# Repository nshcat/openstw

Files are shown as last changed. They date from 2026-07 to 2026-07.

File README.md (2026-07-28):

# openstw

A project aiming to design a physical replica of a German Sp Dr S60 relais signal box panel (_Stelltisch_) with a software simulation of local railway traffic behind it, in order to offer a compelling simulation of the day-to-day work of a signal box operator (_Fahrdienstleiter_).

## Project goals
- **A depiction of a Sp Dr S60 Stelltisch that is as realistic as possible** - This is pretty much the main goal for me. Unlike many other projects on the internet that already saw the light of day, I am not planning on making any compromises when it comes to the visual and functional design of the Stelltisch and its tiles. Even though that is likely never going to happen, I'd want it to be useable as a training aid for train routing controllers, even if only in theory.

- **Easy extensibility when adapting to new Betriebsstellen** - The system should be very modular and easy to configure, such that building replicas of any of the real German Betriebsstellen that employ a Sp Dr S60 signal box is as easy and frictionless as possible. Of course, local oddities will almost always require some degree of customization, such as custom tiles that feature specific colours and signal placements, but my goal is to reduce this work as much as possible, and make it as easy as possible.

- **As little expensive tools needed as possible** - I want the whole project to be buildable with nothing more than a run-of-the-mill 3D printer, access to a PCB manufacturing and assembly service and a set of screwdrivers. This includes not having to pay tons of money for software licenses!

- And of course, **Be completely Open-Source!** - To me, this also implies that all the tools used to make this project a reality should be open-source as well.

## Non-goals
- **Interfacing with model train setups** - I personally am neither interested in nor experienced with model train setups, and thus this project will not be designed or implemented with that in mind. Although the already existing software and hardware architecture design does leave the possibility open, if anyone else dares to try :)

- **Have everything be hand-solderable** - I have decided against this right from the start. The small size of the Stelltisch tiles make it almost a neccasity to use very small SMT components, and since access to PCB assembly is easy and comparatively cheap nowadays, I felt that it would be silly to restrict my design to being hand solderable and risk compromising my goal of realism. And one can still use a stencil, solder paste and a cheap mini hot plate to assemble the boards, if so desired.

## Repository structure

Each sub folder contains its own README file with more detailed information about that specific component of the project. Right now, the project consists of the following components:

 - `hardware`: Contains design files for the various PCBs and 3d-printed components used in the project that make up the physical Stelltisch, and act as the simulator frontend.
 - `software`: The software that simulates the signal box, including simulated time tables and train traffic. This acts as the simulator backend.
 - `firmware`: Firmware for all PCBs that contain a programmable microcontroller. The firmware handles communication with the simulator backend via CAN bus, and controlling and supervising the LEDs and input elements of each Stelltisch tile.

## Glossary
- **Stellwerk** - German term for a signalling box.
- **Fahrdienstleiter** - German term for a signal box operator.
- **Betriebsstelle** - German term for a part of the railway network that often has a Stellwerk associated with it. Often contains a public train station, but doesn't have to.
- **Sp Dr S60** - A specific kind of Stellwerk implementation based on signalling relais technology, developed by Siemens Germany in the 1960's that found wide spread adoption within the German railway infrastructure, and is still in operation today at many Betriebsstellen.
- **Stelltisch** - A big panel made up of rectangular tiles featuring a schematic depiction of the local railway topology and infrastructure of a Betriebsstelle, allowing the Fahrdienstleiter to interact with the local signalling systems to safely setup routes for trains.

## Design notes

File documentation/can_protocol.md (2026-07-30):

# OpenSTW CAN-bus protocol

## Overview

- Messages are exchanged between the host (**H**) and any of the area controllers (**C**)
- The system uses standard CAN frames
- The message ids are used as the CAN frame ids. Messages directed to the controllers start with `0x100`, and messages directed to the host start with `0x000` -allowing easy filtering and inate prioritization of event messages originating from controllers.

## General messages

### Messages overview

| Id | Direction | Name | Description |
|:--- |:--- |:--- |:--- |
| `0x110` | H -> C | MSG_GEN_HEARTBEAT_RQ | Requests a heartbeat response from a specific area controller. |
| `0x011` | C -> H | MSG_GEN_HEARTBEAT_RESP | Heartbeat response from a specific controller. |
| `0x012` | C -> H | MSG_GEN_C_ACK | Controller signals acknowledgement of a previous message. |

### Message payload structure

#### [`0x110`] Heartbeat request (`MSG_GEN_HEARTBEAT_RQ`)

**Length:** 1 byte

**Structure:**

| Byte | Bits | Function | Valid Values |
|:---- |:--- |:--- |:--- |
| `0`  | `[7:0]` | Controller Address | `uint8_t` |

#### [`0x011`] Heartbeat response (`MSG_GEN_HEARTBEAT_RESP`)

**Length:** 1 byte

**Structure:**

| Byte | Bits | Function | Valid Values |
| ---- | --- | --- | --- |
| `0`  | `[7:0]` | Controller Address | `uint8_t` |

#### [`0x012`] Message acknowledged by controller (`MSG_GEN_C_ACK`)

**Length:** 2 bytes

**Structure:**

| Byte | Bits | Function | Valid Values |
| ---- | --- | --- | --- |
| `0`  | `[7:0]` | Controller Address | `uint8_t` |
| `1`  | `[7:0]` | Message cookie | `uint8_t` |

## Input and Output

### Messages overview

| Id | Direction | Name | Description |
| --- | --- | --- | --- |
| `0x120` | H -> C | MSG_IO_CONF_LEDS | Configures LED layout of a specific controller |
| `0x121` | H -> C | MSG_IO_SET_LEDS_CH0 | Set state of up to 3 LEDs on channel 0 |
| `0x122` | H -> C | MSG_IO_SET_LEDS_CH1 | Set state of up to 3 LEDs on channel 1 |
| `0x023` | C -> H | MSG_IO_BTT_STATE | Reports the state of a button |

### Message payload structure

#### [`0x120`] Configure LEDs (`MSG_IO_CONF_LEDS`)

**Length:** 4 bytes

**Structure:**

| Byte | Bits | Function | Valid Values |
| ---- | --- | --- | --- |
| `0`  | `[7:0]` | Controller Address | `uint8_t` |
| `1`  | `[7:0]` | Message cookie | `uint8_t` |
| `2`  | `[7:0]` | Number of LEDs (Channel 0) | `uint8_t` |
| `3`  | `[7:0]` | Number of LEDs (Channel 1) | `uint8_t` |

#### [`0x121`] Set state of LEDs on channel 0 (`MSG_IO_SET_LEDS_CH0`)

Sets the state of up to three LEDs connected to channel 0 of a specific area controller. Passing an LED index value of `0xFF` signals that no LED state should be changed for that part of the payload.

**Length:** 8 bytes

**Structure:**

| Byte | Bits | Function | Valid Values |
| ---- | --- | --- | --- |
| `0`  | `[7:0]` | Controller Address | `uint8_t` |
| `1`  | `[7:0]` | Message Cookie | `uint8_t` |
| `2`  | `[7:0]` | LED 1 Index | `[0, 254]`, `0xFF` means "None" |
| `3`  | | LED 1 State | |
| | `[1:0]` | Mode | `0b00`: Off, `0b01`: On, `0b10`: Blink |
| | `[4:2]` | Color | `0b000`: White, `0b001`: Red, `0b010`: Green, `0b011`: Yellow, `0b100`: Blue |
| `4`  | `[7:0]` | LED 2 Index | `[0, 254]`, `0xFF` means "None" |
| `5`  | | LED 2 State | _see above_ |
| `6`  | `[7:0]` | LED 3 Index | `[0, 254]`, `0xFF` means "None" |
| `7`  | | LED 3 State | _see above_ |

#### [`0x122`] Set state of LEDs on channel 1 (`MSG_IO_SET_LEDS_CH1`)

**Length:** 8 bytes

**Structure:**

| Byte | Bits | Function | Valid Values |
| ---- | --- | --- | --- |
| `0`  | `[7:0]` | Controller Address | `uint8_t` |
| `1`  | `[7:0]` | Message Cookie | `uint8_t` |
| `2`  | `[7:0]` | LED 1 Index | `[0, 254]`, `0xFF` means "None" |
| `3`  | | LED 1 State | |
| | `[1:0]` | Mode | `0b00`: Off, `0b01`: On, `0b10`: Blink |
| | `[4:2]` | Color | `0b000`: White, `0b001`: Red, `0b010`: Green, `0b011`: Yellow, `0b100`: Blue |
| `4`  | `[7:0]` | LED 2 Index | `[0, 254]`, `0xFF` means "None" |
| `5`  | | LED 2 State | _see above_ |
| `6`  | `[7:0]` | LED 3 Index | `[0, 254]`, `0xFF` means "None" |
| `7`  | | LED 3 State | _see above_ |

#### [`0x023`] Report button state (`MSG_IO_BTT_STATE`)

**Length:** 3 bytes

**Structure:**

| Byte | Bits | Function | Valid Values |
| ---- | --- | --- | --- |
| `0`  | `[7:0]` | Controller Address | `uint8_t` |
| `1`  | `[7:0]` | Button index | `uint8_t` |
| `2`  | `[7:0]` | Button state | `0x0`: Released, `0x1`: Pressed |

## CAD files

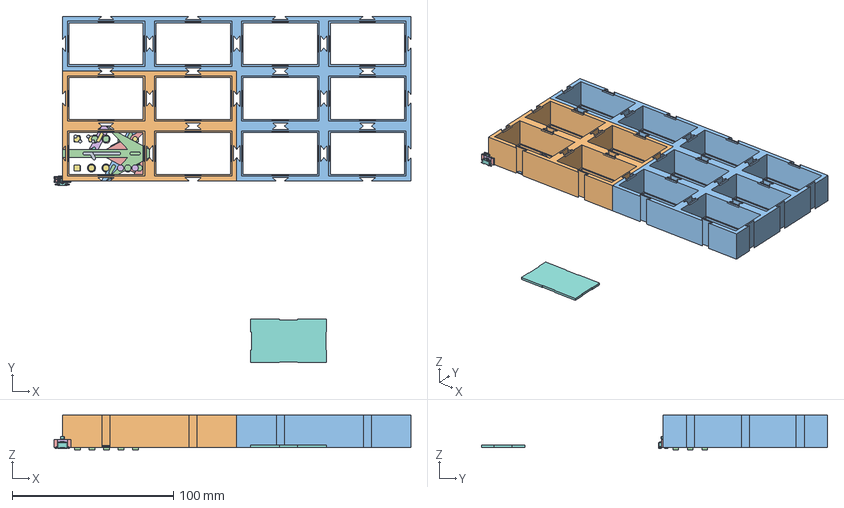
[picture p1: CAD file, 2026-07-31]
hardware/3d_components/stelltisch.FCStd
221.2 x 214.6 x 21.4 mm
track_straight_faceplate_lightpipe
frame_2x2
frame_5x3
test_pcb_leds
track_str_hpvrblk_lightpipe
sw_wd_A_inlay
sw_wd_A_lightpipe
track_bent_A_up_lightpipe
track_bent_A_down_lightpipe
prellbock_inlay
switch_cross_A_inlay
switch_cross_A_lightpipe
track_diag_br_inlay
track_straight_zs2_lightpipe
track_straight_asigsh_lightpipe
track_straight_vr_lightpipe
track_straight_vr_conn_light_pipe
track_straight_asigsh_conn_lightpipe
track_straight_sh_lightpipe
track_noindc_straight_right_arrow_out_inlay
track_noindc_straight_right_arrow_in_inlay
track_noindc_straight_right_arrow_out_sig_lightpipe
C_0402_1005Metric
C_0402_1005Metric002
C_0402_1005Metric004
零件3
零件001
零件002
零件003
C_0402_1005Metric006
C_0402_1005Metric008
零件004
C_0402_1005Metric010
C_0402_1005Metric012
零件005
零件006
零件007
零件008
零件009
C_0402_1005Metric014
C_0402_1005Metric016
零件010
C_0402_1005Metric018
C_0402_1005Metric020
零件011
零件012
零件013
C_0402_1005Metric022
零件014
C_0402_1005Metric024
C_0402_1005Metric026
C_0402_1005Metric028
CONN-SMD_5P-P1.50_ZX-ZH1.5-5PLT
CONN-SMD_2P-P1.50_ZX-ZH1.5-2PLT
CONN-SMD_5P-P1.50_ZX-ZH1.5-5PLT002
tile_light_pcb_PCB
C_0402_1005Metric030
C_0402_1005Metric032
C_0402_1005Metric034
零件015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

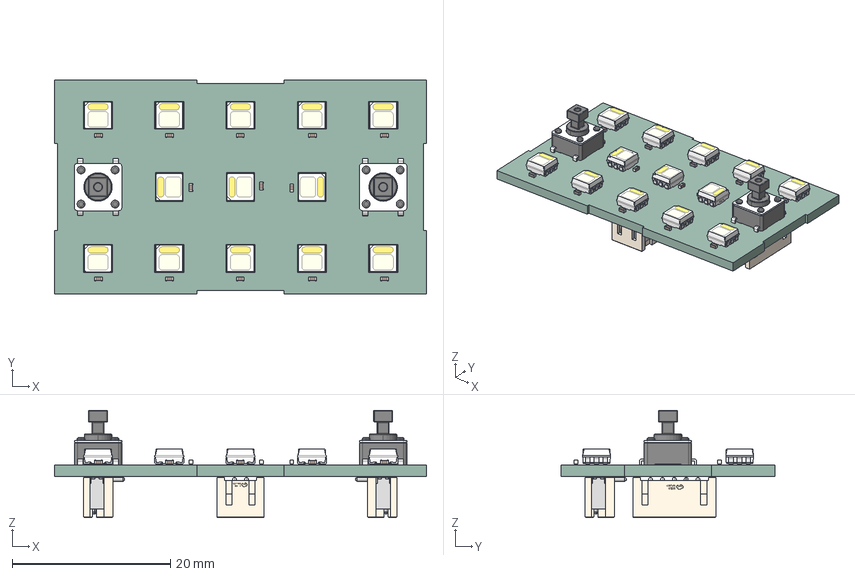
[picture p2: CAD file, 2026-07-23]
hardware/pcbs/tile_pcb_typeA/renders/tile_light_pcb_mod2_t.step
47.0 x 27.0 x 13.6 mm
C_0402_1005Metric x 15
零件3 x 15
SW-SMD_4P-L6.0-W6.0-P4.50-LS9.0-H7.3 x 2
CONN-SMD_5P-P1.50_ZX-ZH1.5-5PLT x 2
CONN-SMD_2P-P1.50_ZX-ZH1.5-2PLT
tile_light_pcb_PCB

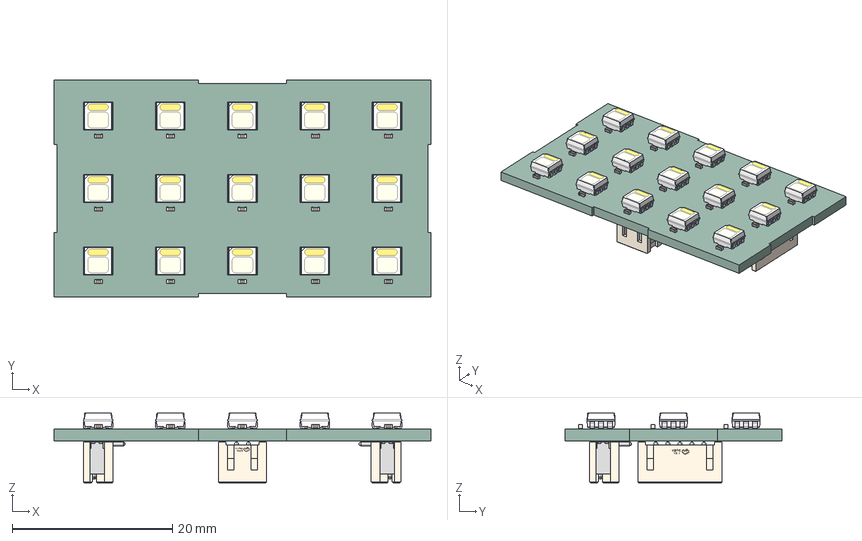
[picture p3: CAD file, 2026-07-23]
hardware/pcbs/tile_pcb_typeA/renders/tile_light_pcb.step
47.0 x 27.0 x 8.68 mm
C_0402_1005Metric x 15
零件3 x 15
CONN-SMD_5P-P1.50_ZX-ZH1.5-5PLT x 2
CONN-SMD_2P-P1.50_ZX-ZH1.5-2PLT
tile_light_pcb_PCB

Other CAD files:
hardware/pcbs/tile_pcb_typeA/renders/tile_light_pcb_mod1.step
hardware/pcbs/tile_pcb_typeA/renders/tile_light_pcb_mod1.stl

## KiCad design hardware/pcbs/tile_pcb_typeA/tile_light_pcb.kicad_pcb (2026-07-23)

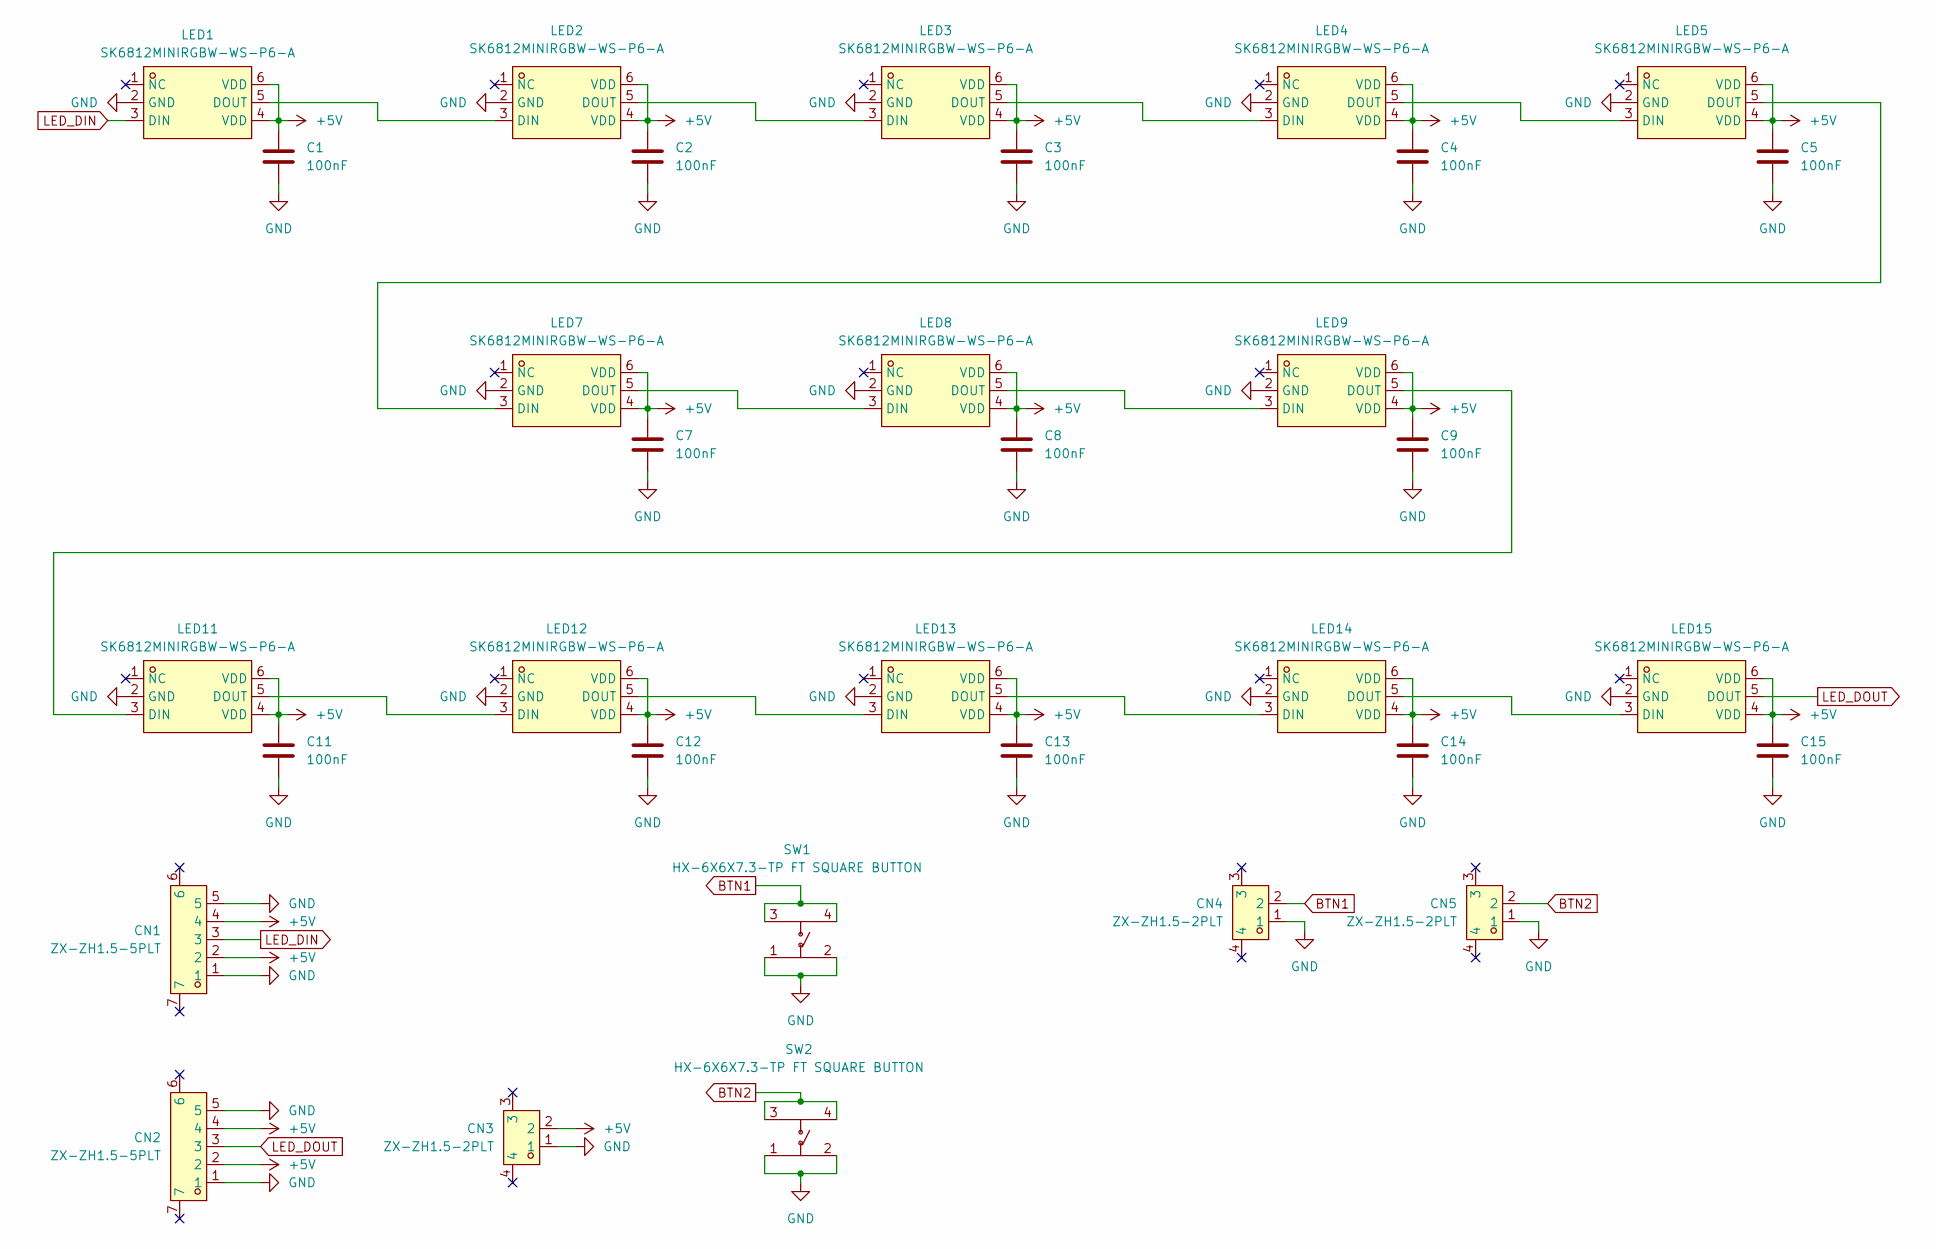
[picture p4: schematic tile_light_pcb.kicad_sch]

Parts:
C1, C2, C3, C4, C5, C7, C8, C9, C11, C12, C13, C14, C15: 100nF; C_0402_1005Metric; LCSC Part # C60474
CN1, CN2: ZX-ZH1.5-5PLT; CONN-SMD_5P-P1.50_ZX-ZH1.5-5PLT; LCSC Part C19272417
CN3, CN4, CN5: ZX-ZH1.5-2PLT; CONN-SMD_2P-P1.50_ZX-ZH1.5-2PLT; LCSC Part C19272414
LED1, LED2, LED3, LED4, LED5, LED7, LED8, LED9, LED11, LED12, LED13, LED14, LED15: SK6812MINIRGBW-WS-P6-A; LED-SMD_6P-L3.5-W3.5_SK6812MINIRGBW-WS-P6-A; MPN SK6812MINIRGBW-WS-P6-A; LCSC Part C7423106
SW1, SW2: HX-6X6X7.3-TP FT SQUARE BUTTON; SW-SMD_4P-L6.0-W6.0-P4.50-LS9.0-H7.3; MPN HX-6x6x7.3-TP FT square button; LCSC Part C49234152

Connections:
+5V: C1.2, C2.2, C3.2, C4.2, C5.2, C7.2, C8.2, C9.2, C11.2, C12.2, C13.2, C14.2, C15.2, CN1.2, CN1.4, CN2.2, CN2.4, CN3.2, LED1.4 (VDD), LED1.6 (VDD), LED2.4 (VDD), LED2.6 (VDD), LED3.4 (VDD), LED3.6 (VDD), LED4.4 (VDD), LED4.6 (VDD), LED5.4 (VDD), LED5.6 (VDD), LED7.4 (VDD), LED7.6 (VDD), LED8.4 (VDD), LED8.6 (VDD), LED9.4 (VDD), LED9.6 (VDD), LED11.4 (VDD), LED11.6 (VDD), LED12.4 (VDD), LED12.6 (VDD), LED13.4 (VDD), LED13.6 (VDD), LED14.4 (VDD), LED14.6 (VDD), LED15.4 (VDD), LED15.6 (VDD)
BTN1: CN4.2, SW1.3, SW1.4
BTN2: CN5.2, SW2.3, SW2.4
GND: C1.1, C2.1, C3.1, C4.1, C5.1, C7.1, C8.1, C9.1, C11.1, C12.1, C13.1, C14.1, C15.1, CN1.1, CN1.5, CN2.1, CN2.5, CN3.1, CN4.1, CN5.1, LED1.2 (GND), LED2.2 (GND), LED3.2 (GND), LED4.2 (GND), LED5.2 (GND), LED7.2 (GND), LED8.2 (GND), LED9.2 (GND), LED11.2 (GND), LED12.2 (GND), LED13.2 (GND), LED14.2 (GND), LED15.2 (GND), SW1.1, SW1.2, SW2.1, SW2.2
LED_DIN: CN1.3, LED1.3 (DIN)
LED_DOUT: CN2.3, LED15.5 (DOUT)
unnamed: LED1.5 (DOUT), LED2.3 (DIN)
unnamed: LED2.5 (DOUT), LED3.3 (DIN)
unnamed: LED3.5 (DOUT), LED4.3 (DIN)
unnamed: LED4.5 (DOUT), LED5.3 (DIN)
unnamed: LED5.5 (DOUT), LED7.3 (DIN)
unnamed: LED7.5 (DOUT), LED8.3 (DIN)
unnamed: LED8.5 (DOUT), LED9.3 (DIN)
unnamed: LED9.5 (DOUT), LED11.3 (DIN)
unnamed: LED11.5 (DOUT), LED12.3 (DIN)
unnamed: LED12.5 (DOUT), LED13.3 (DIN)
unnamed: LED13.5 (DOUT), LED14.3 (DIN)
unnamed: LED14.5 (DOUT), LED15.3 (DIN)

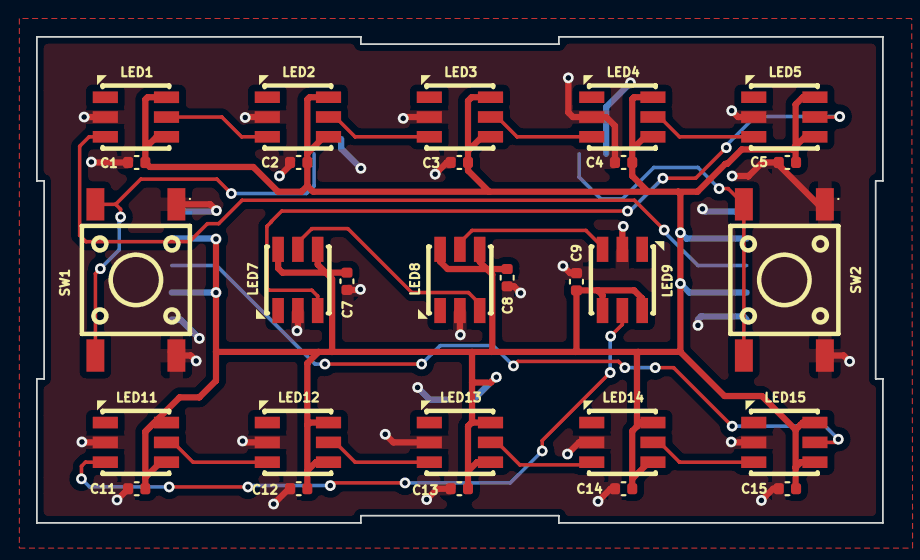
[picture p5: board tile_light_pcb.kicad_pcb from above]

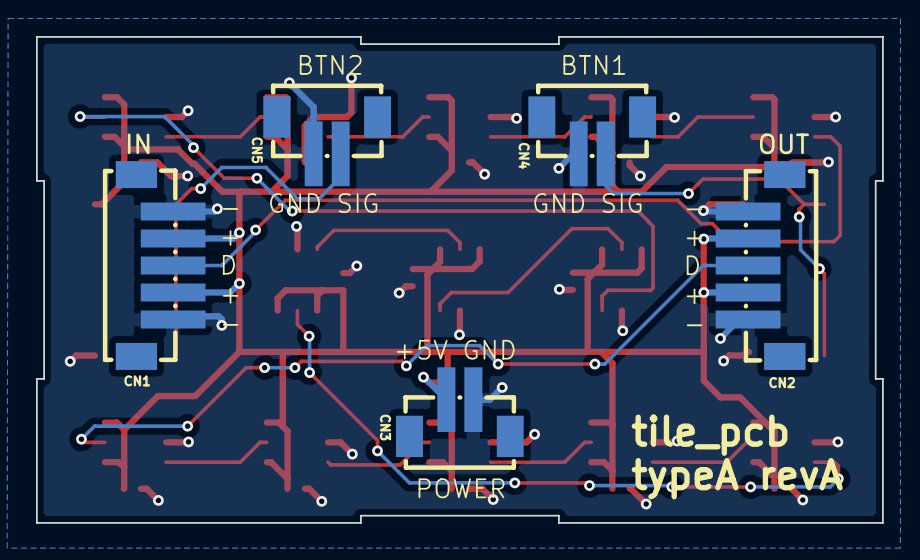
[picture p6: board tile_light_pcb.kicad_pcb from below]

Board: 2 copper layers, 47.0 x 27.0 mm, 33 parts (5 on the bottom side), 18 nets.

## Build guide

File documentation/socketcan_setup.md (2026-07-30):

# Setting up USB2CAN adapter via `socketcan`

- `sudo slcand -f -o -c -s5 /dev/ttyACM0`

- `sudo ip link set can0 up type can bitrate 800000`

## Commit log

2025-08-27 Work on track rendering
2025-08-29 Simple track rendering
2025-09-06 Implemented track label boxes
2025-09-06 Implemented ZNA blinking (and global timer which was required for this)
2025-09-06 Moved simulation into background thread
2025-09-10 Implemented MDI interface, and magnets
2025-09-10 Implemented magnet rotation
2025-09-10 Implemented more magnets
2025-09-10 Implemented the rest of the magnets
2025-09-24 WIP work on switches
2025-10-03 WIP more work on switch rendering
2025-10-03 WIP switch rendering
2026-07-11 hardware: stelltisch: First work on tile frame
    [stelltisch.FCStd]
2026-07-11 hardware: stelltisch: Finished tile frame, and modeled empty face plate
    [stelltisch.FCStd]
2026-07-11 hardware: stelltisch: Adjusted face plate clip pockets slightly to have more tolerance
    [stelltisch.FCStd]
2026-07-12 hardware: stelltisch: Lots more work on tile face plates, fixed tolerance issues and wrong direction of clip pockets, and modeled straight track face plate
    [stelltisch.FCStd]
2026-07-12 hardware: stelltisch: Designed light shade for empty tile (which acts as a spacer), and light shade for straight track segment
    [stelltisch.FCStd]
2026-07-12 hardware: stelltisch: Small cad file fixes
    [stelltisch.FCStd]
2026-07-12 hardware: stelltisch: Add assembly of a tile
    [stelltisch.FCStd]
2026-07-12 hardware: stelltisch: Added 2x2 frame
    [stelltisch.FCStd]
2026-07-12 hardware: stelltisch: Added notches to the lightshade insert in order to pass by the mounting clips of the frame more easily
    [stelltisch.FCStd]
2026-07-13 hardware: stelltisch: work on test pcb, and adjusted assembly
    [stelltisch.FCStd]
2026-07-13 hardware: stelltisch: Added lots of measurements from the real STW, and added grid for lamp placement
    [stelltisch.FCStd]
2026-07-13 hardware: stelltisch: Modelled straight track with hauptsignal and distance signal
    [stelltisch.FCStd]
2026-07-14 hardware: stelltisch: reduced light pipe depth
    [stelltisch.FCStd]
2026-07-14 hardware: stelltisch: designed a switch:
    [stelltisch.FCStd]
2026-07-15 hardware: stelltisch: designed a bent track element
    [stelltisch.FCStd]
2026-07-15 hardware: stelltisch: designed another bent track element
    [stelltisch.FCStd]
2026-07-15 hardware: stelltisch: designed prellbock tile
    [stelltisch.FCStd]
2026-07-15 hardware: stelltisch: designed cross switch tile
    [stelltisch.FCStd]
2026-07-15 hardware: stelltisch: designed cross switch tile <- fix naming
    [stelltisch.FCStd]
2026-07-15 hardware: stelltisch: designed diagonal track element
    [stelltisch.FCStd]
2026-07-19 hardware: stelltisch: designed track with Zs2
    [stelltisch.FCStd]
2026-07-19 hardware: stelltisch: designed straight track with Asig and Sh
    [stelltisch.FCStd]
2026-07-19 hardware: stelltisch: fixed Asig inlay z pos
    [stelltisch.FCStd]
2026-07-19 hardware: stelltisch: designed tile with track and distant signal
    [stelltisch.FCStd]
2026-07-19 hardware: stelltisch: designed connected Asig and Vr tiles
    [stelltisch.FCStd]
2026-07-19 hardware: stelltisch: designed tile with Sh
    [stelltisch.FCStd]
2026-07-19 hardware: stelltisch: designed some arrow tiles
    [stelltisch.FCStd]
2026-07-19 hardware: stelltisch: designed some more arrow tiles..
    [stelltisch.FCStd]
2026-07-19 hardware: stelltisch: fixed some smaller issues with the CAD project
    [stelltisch.FCStd]
2026-07-23 hardware: tile light pcb: Added PCB that lights up most of the general signalling tiles
    [tile_light_pcb.kicad_pcb, tile_light_pcb.kicad_sch]
2026-07-23 hardware: stelltisch: imported PCB 3d render
    [stelltisch.FCStd]
2026-07-23 hardware: tile light pcb: Added buttons and did routing
    [tile_light_pcb.kicad_pcb, tile_light_pcb.step, tile_light_pcb_mod1.step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]
2026-07-23 hardware: tile light pcb: Finished revA of pcb
    [tile_light_pcb.kicad_sch]
2026-07-23 hardware: tiles: smaller changes
    [stelltisch.FCStd]
2026-07-24 software: added openstw-topo subproject that will contain rail topology handling
2026-07-28 hardware: renamed tile light pcb to tile pcb type A, for clarity
    [tile_light_pcb.kicad_pcb, tile_light_pcb.kicad_sch, tile_light_pcb.step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]
2026-07-28 hardware: added kicad project for the area controller pcb
    [area_controller.kicad_pcb, area_controller.kicad_sch]
2026-07-30 docs: Added first draft of CAN bus protocol
2026-07-30 docs, tools: Added `socketcan` test script, and some info on how to set up the USB2CAN adapter
2026-07-31 hardware: tiles: Lots of work on tile lightshades
    [stelltisch.FCStd]
2026-07-31 hardware: tiles: Added light shade element for tile with connected distant signal
    [stelltisch.FCStd]
2026-10-30 software: spdr: Work on buttons on tiles, and renamed DisplayElement to Aperture
2026-10-30 software: spdr: More work on buttons, input processing ideas, project structure.
2026-10-31 software: interlocking: Implemented axle counter links and track section
2026-10-31 software: interlocking: Moved axle counter helper classes out of elements/ subdirectory
2026-11-01 software: topology: Switched to using QDomDocument for XML parsing
2026-11-07 software: interlocking: Extended signals and switches to refer to their corresponding topology node, and fleshed out switches to allow position set point and switching
2026-11-07 software: topotest: Added axle counters to TestStadt XML file
2026-11-07 software: interlocking: Add XML parsing of track sections and switches
2026-11-07 software: interlocking: Reworked the data flow for setting signal aspects fundamentally. Previously, the system was set-up such that setting a specific aspect on a main signal triggered a creation of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
2026-11-12 software: gui: Implemented global blink timer
